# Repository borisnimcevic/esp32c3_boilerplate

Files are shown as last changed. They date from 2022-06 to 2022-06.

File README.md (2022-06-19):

# ESP32-C3 minimum components to start a project

### Motivation:
The plan is to copy this project every time a new project based on the esp32c3 starts.

### TODO:
* make a script for renaming all the relevant files for KiCAD to the name of the project
* Update the Bill Of materials

### Bill Of Materials
|Component  |Quantity |Link |
|----- |----- |-----  |
|ESP32-C3 |1 |[digikey](https://www.digikey.se/en/products/detail/espressif-systems/ESP32-C3/14115579) |
|or with embedded flash (ESP32-C3FN4) |1 |[digikey](https://www.digikey.se/en/products/detail/espressif-systems/ESP32-C3FN4/14115581) |
|FLASH 4MBIT |1 |[digikey](https://www.digikey.se/en/products/detail/winbond-electronics/W25Q16JVSSIM/12143335) |
|resistor 100 0402 |7 |[digikey](https://www.digikey.se/en/products/detail/yageo/RC0402FR-07100RP/4935263) |
|resistor 10k 0402 |1 |[digikey](https://www.digikey.se/en/products/detail/yageo/RC0402FR-0710KP/4935264) |
|LED red 0603|30 |[digikey](https://www.digikey.se/en/products/detail/osram-opto-semiconductors-inc/LS-Q976-NR-1/1227986) |
|LED transistor driver |4 |[digikey](https://www.digikey.se/en/products/detail/micro-commercial-co/MMBT5550-TP/10054662) |
|Ceramic antenna (chip antenna)|1 |[digikey](https://www.digikey.se/en/products/detail/johanson-technology-inc/2450AT18A100E/1560676) |
|Ceramic capacitor 1pF |1 |[digikey](https://www.digikey.se/en/products/detail/johanson-technology-inc/500R07S1R0BV4T/1561521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) |
|Ceramic capacitor 10nF |1 |[digikey](https://www.digikey.se/en/products/detail/tdk-corporation/CGA2B2X5R1E103M050BA/3949410) |
|Ceramic capacitor 100nF |1 |[digikey](https://www.digikey.se/en/products/detail/tdk-corporation/CGA2B1X7R1C104M050BC/3949478) |
|Ceramic capacitor 1uF |1 |[digikey](https://www.digikey.se/en/products/detail/kyocera-avx/04023D105KAT2A/13557232) |
|Ceramic capacitor 4.7uF |1 |[digikey](https://www.digikey.se/en/products/detail/yageo/CC0402KRX5R5BB475/7164360) |
|Ceramic inductor 2.7nH |1 |[digikey](https://www.digikey.se/en/products/detail/johanson-technology-inc/L-07C2N7SV6T/1830166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) |
|Ceramic inductor 3.9nH |1 |[digikey](https://www.digikey.se/en/products/detail/johanson-technology-inc/L-07C3N9SV6T/1915227) |
|Ceramic inductor 39nH |1 |[digikey](https://www.digikey.se/en/products/detail/johanson-technology-inc/L-07C39NJV6T/1915226) |

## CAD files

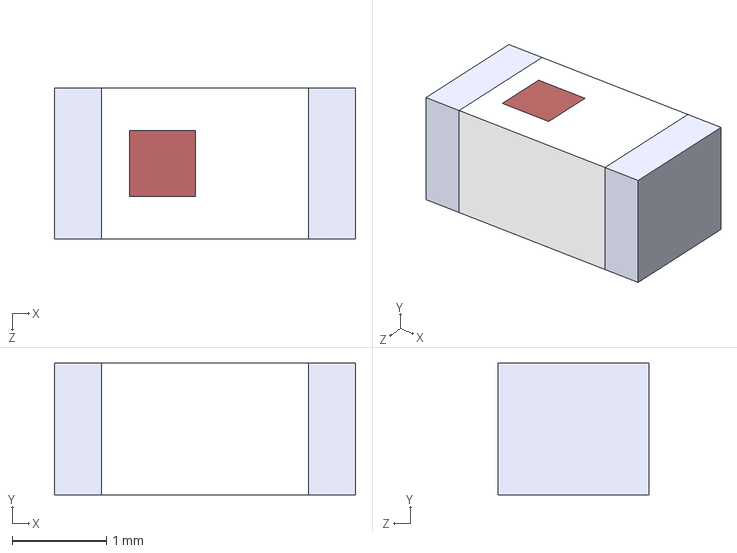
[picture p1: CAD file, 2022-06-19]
hardware/kicad-parts/ANT-2450AT18A100E/2450AT18A100E.step
3.20 x 1.40 x 1.60 mm

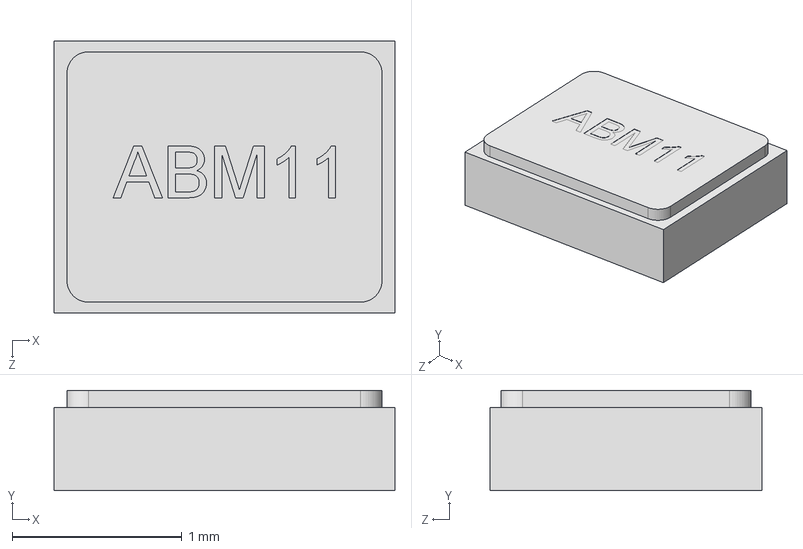
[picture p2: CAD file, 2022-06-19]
hardware/kicad-parts/Crystal/ABM1116.000MHZ-B7GT.STEP
2.01 x 0.59 x 1.60 mm

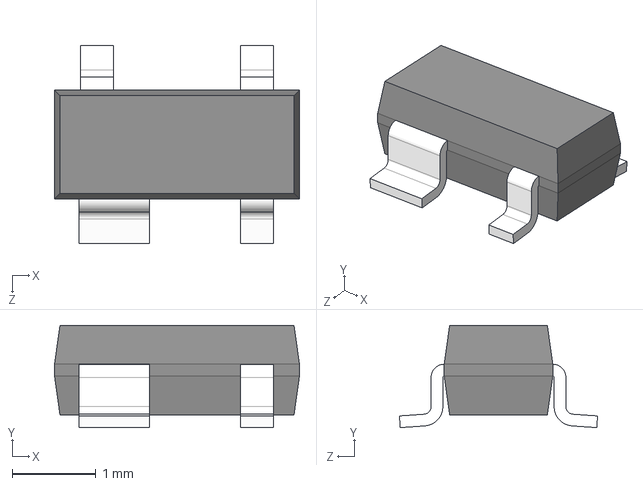
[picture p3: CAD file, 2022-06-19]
hardware/kicad-parts/ESD_protection-SR05/SR05.step
2.92 x 1.22 x 2.36 mm

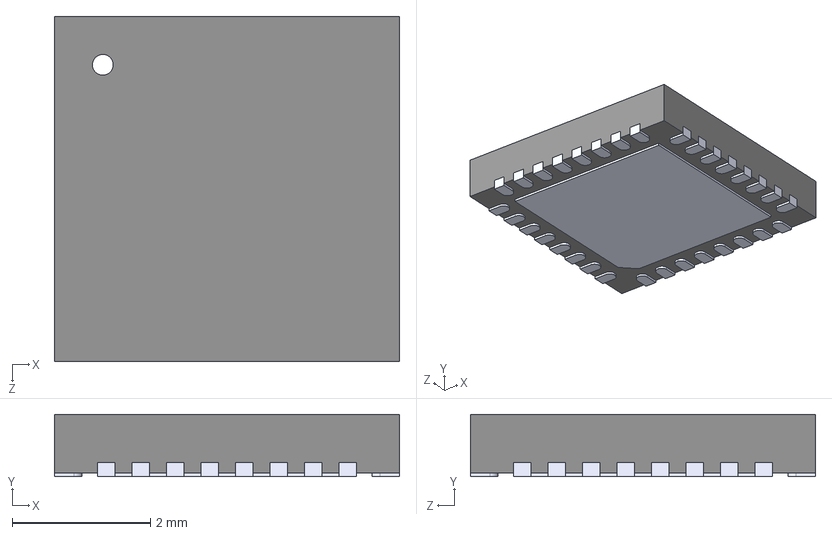
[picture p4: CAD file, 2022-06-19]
hardware/kicad-parts/ESP32-C3/ESP32-C3FH4.step
5.00 x 0.9 x 5.00 mm

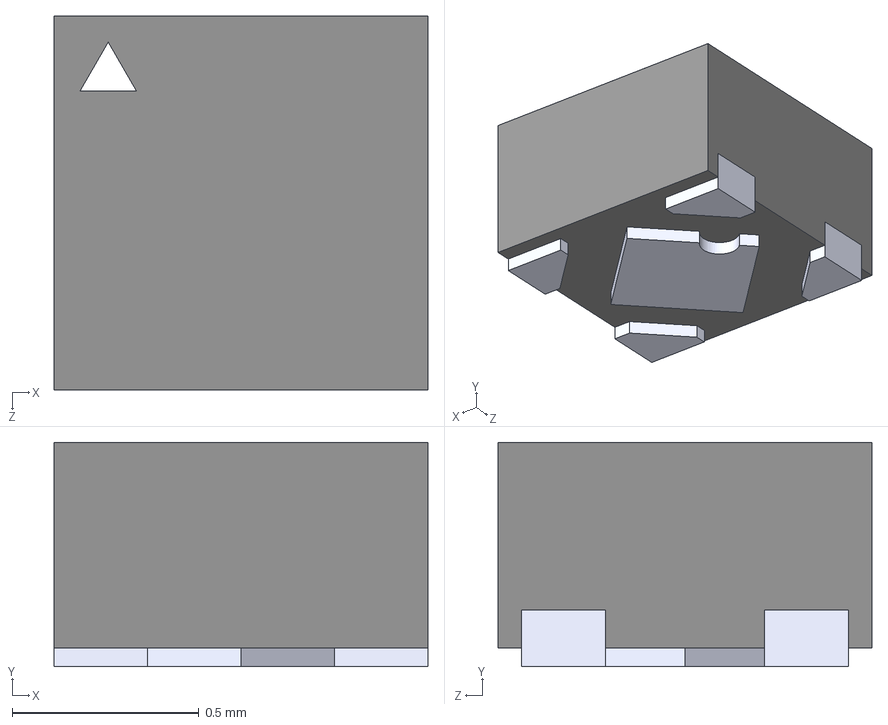
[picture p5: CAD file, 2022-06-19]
hardware/kicad-parts/LDO-MIC5524-3-3YMT-TZ/MIC5524-3.3YMT-TZ.step
1.00 x 0.6 x 1.00 mm

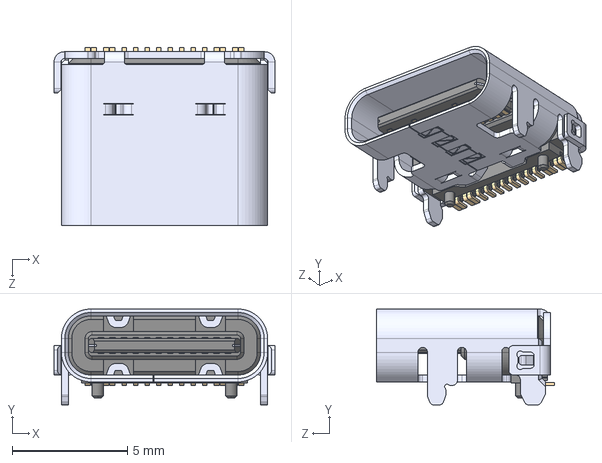
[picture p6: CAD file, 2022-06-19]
hardware/kicad-parts/USBC-USB4105-GF-A/USB4105-GF-A.step
9.58 x 4.16 x 7.71 mm

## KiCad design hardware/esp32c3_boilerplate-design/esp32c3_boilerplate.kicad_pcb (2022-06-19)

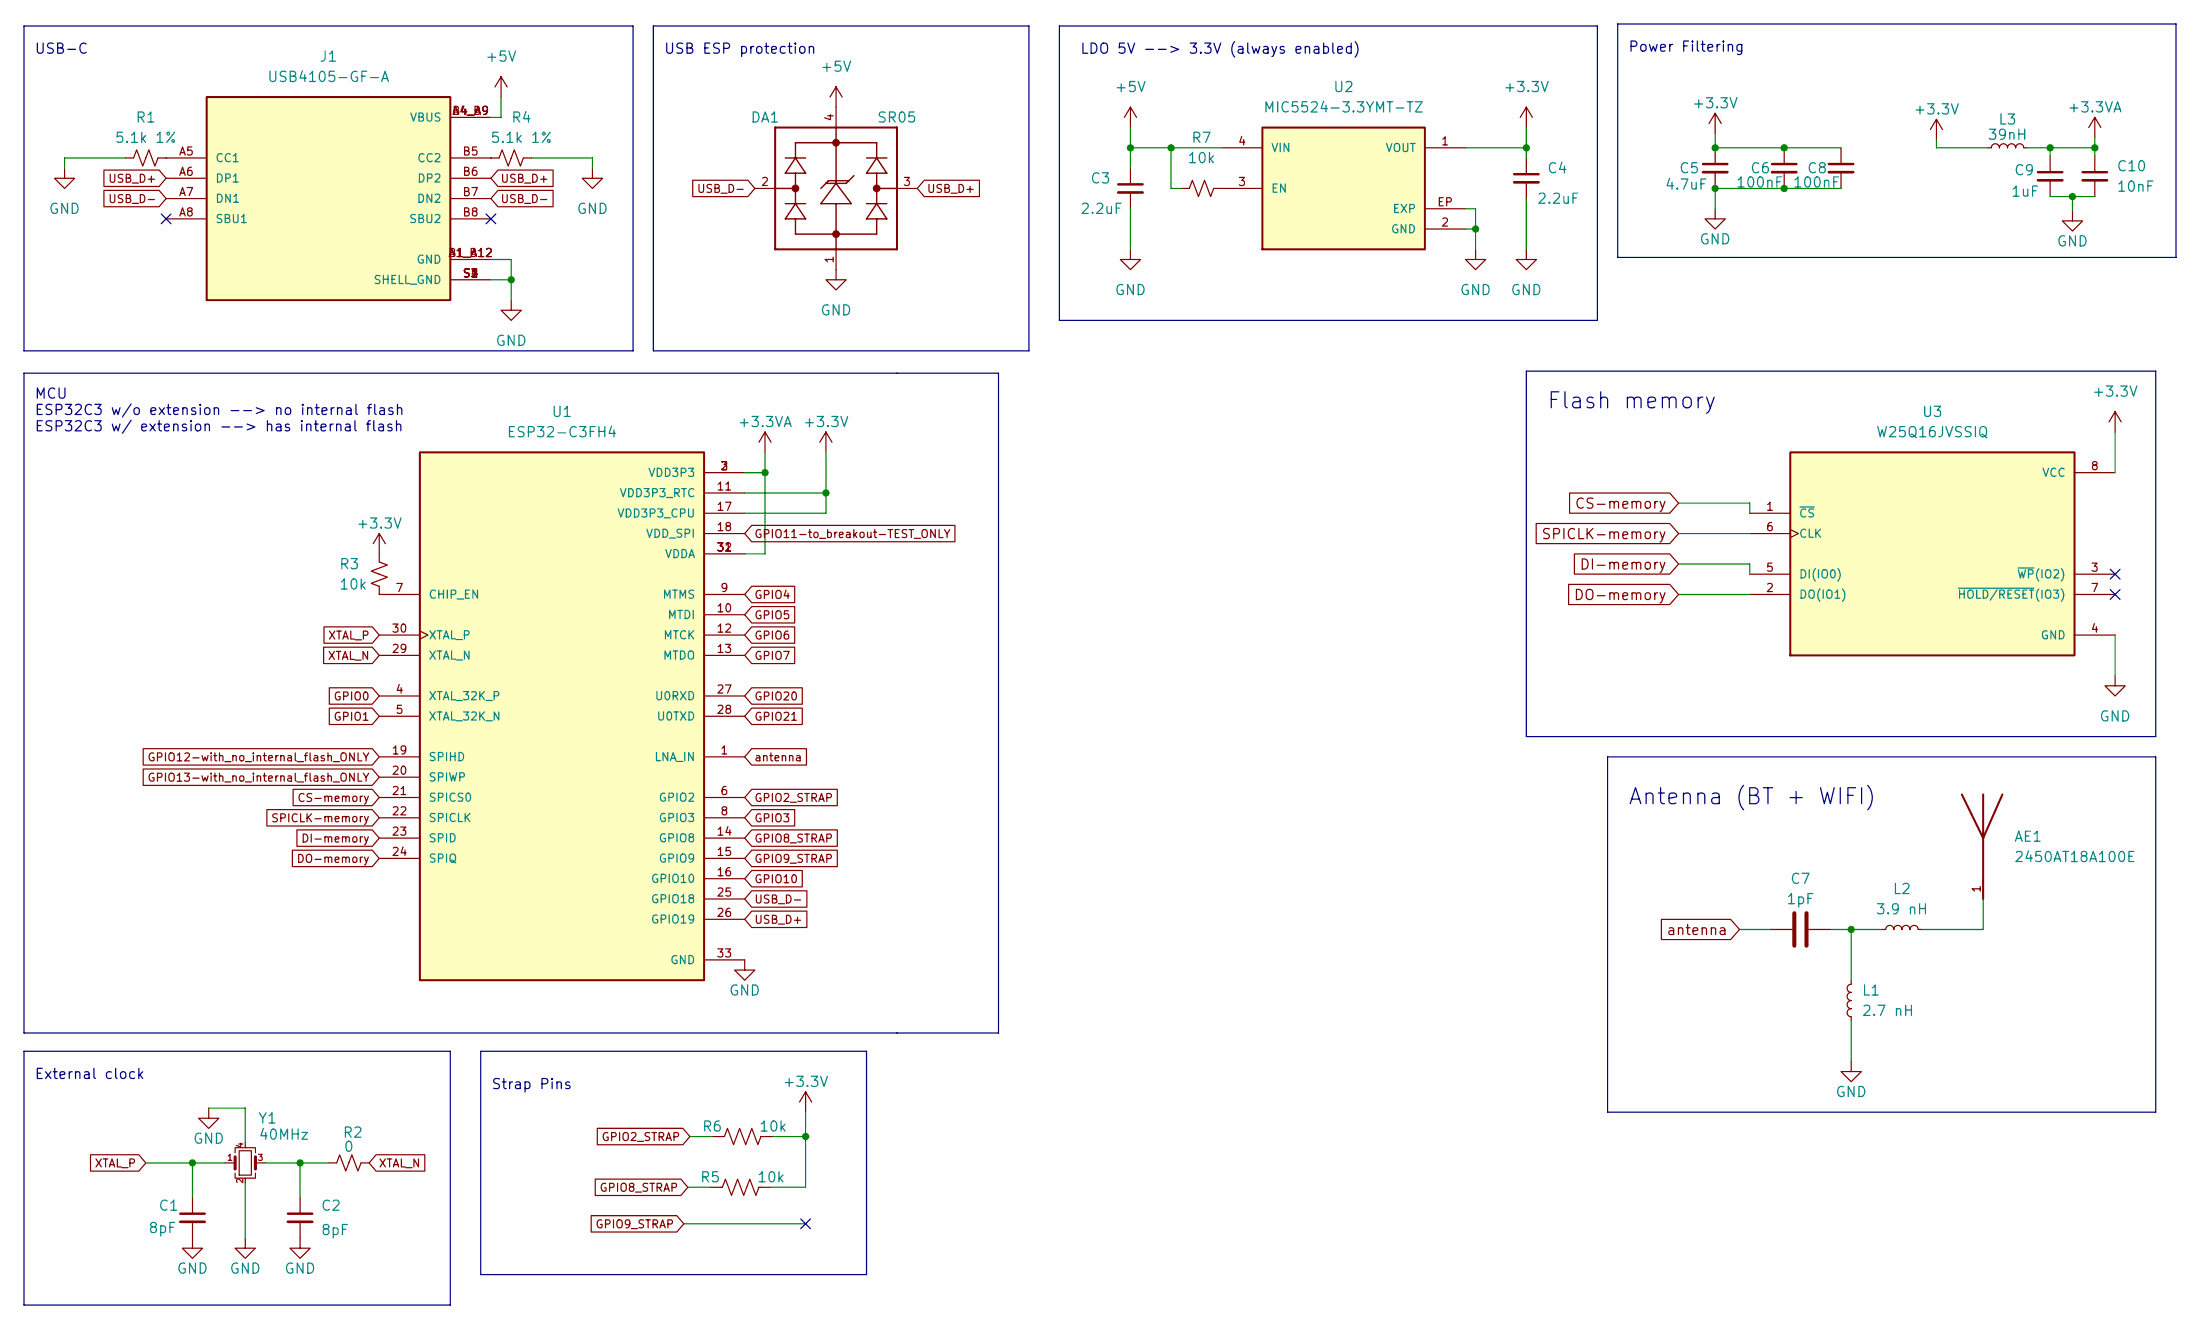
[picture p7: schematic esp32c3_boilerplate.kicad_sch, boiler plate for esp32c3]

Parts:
AE1: 2450AT18A100E; ANTC3216X140N; PARTREV 1.3
C1, C2: 8pF; C_0402_1005Metric_Pad0.74x0.62mm_HandSolder
C3, C4: 2.2uF; C_0402_1005Metric_Pad0.74x0.62mm_HandSolder
C5: 4.7uF; L_0402_1005Metric
C6, C8: 100nF; L_0402_1005Metric
C7: 1pF; C_0402_1005Metric
C9: 1uF; L_0402_1005Metric
C10: 10nF; L_0402_1005Metric
DA1: SR05; SOT143
J1: USB4105-GF-A; GCT_USB4105-GF-A; PARTREV A3
L1: 2.7 nH; L_0402_1005Metric
L2: 3.9 nH; L_0402_1005Metric
L3: 39nH; L_0402_1005Metric
R1, R4: 5.1k 1%; R_0402_1005Metric_Pad0.72x0.64mm_HandSolder
R2: 0; R_01005_0402Metric_Pad0.57x0.30mm_HandSolder
R3: 10k; R_01005_0402Metric_Pad0.57x0.30mm_HandSolder
R5, R6: 10k; R_0402_1005Metric
R7: 10k; R_0402_1005Metric_Pad0.72x0.64mm_HandSolder
U1: ESP32-C3FH4; QFN50P500X500X90-33N; PARTREV V1.0
U2: MIC5524-3.3YMT-TZ; VREG_MIC5524-3.3YMT-TZ; PARTREV 1.0
U3: W25Q16JVSSIQ; SOIC127P790X216-8N
Y1: 40MHz; Crystal_SMD_2016-4Pin_2.0x1.6mm

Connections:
+3.3VA: C9.1, C10.1, L3.2, U1.2 (VDD3P3), U1.3 (VDD3P3), U1.31 (VDDA), U1.32 (VDDA)
+3V3: C4.1, C5.1, C6.1, C8.1, L3.1, R3.1, R5.2, R6.2, U1.11 (VDD3P3_RTC), U1.17 (VDD3P3_CPU), U2.1 (VOUT), U3.8 (VCC)
+5V: C3.1, DA1.4, J1.A4_B9 (VBUS), J1.B4_A9 (VBUS), R7.1, U2.4 (VIN)
CS-memory: U1.21 (SPICS0), U3.1 (~CS)
DI-memory: U1.23 (SPID), U3.5 (DI(IO0))
DO-memory: U1.24 (SPIQ), U3.2 (DO(IO1))
GND: C1.2, C2.2, C3.2, C4.2, C5.2, C6.2, C8.2, C9.2, C10.2, DA1.1, J1.A1_B12 (GND), J1.B1_A12 (GND), J1.S1 (SHELL_GND), J1.S2 (SHELL_GND), J1.S3 (SHELL_GND), J1.S4 (SHELL_GND), L1.1, R1.1, R4.2, U1.33 (GND), U2.2 (GND), U2.EP (EXP), U3.4 (GND), Y1.2, Y1.4
GPIO0: U1.4 (XTAL_32K_P)
GPIO1: U1.5 (XTAL_32K_N)
GPIO2_STRAP: R6.1, U1.6 (GPIO2)
GPIO3: U1.8 (GPIO3)
GPIO4: U1.9 (MTMS)
GPIO5: U1.10 (MTDI)
GPIO6: U1.12 (MTCK)
GPIO7: U1.13 (MTDO)
GPIO8_STRAP: R5.1, U1.14 (GPIO8)
GPIO9_STRAP: U1.15 (GPIO9)
GPIO10: U1.16 (GPIO10)
GPIO11-to_breakout-TEST_ONLY: U1.18 (VDD_SPI)
GPIO12-with_no_internal_flash_ONLY: U1.19 (SPIHD)
GPIO13-with_no_internal_flash_ONLY: U1.20 (SPIWP)
GPIO20: U1.27 (U0RXD)
GPIO21: U1.28 (U0TXD)
unnamed: AE1.1, L2.2
unnamed: C2.1, R2.1, Y1.3
unnamed: C7.2, L1.2, L2.1
unnamed: J1.A5 (CC1), R1.2
unnamed: J1.B5 (CC2), R4.1
unnamed: R3.2, U1.7 (CHIP_EN)
unnamed: R7.2, U2.3 (EN)
SPICLK-memory: U1.22 (SPICLK), U3.6 (CLK)
USB_D+: DA1.3, J1.A6 (DP1), J1.B6 (DP2), U1.26 (GPIO19)
USB_D-: DA1.2, J1.A7 (DN1), J1.B7 (DN2), U1.25 (GPIO18)
XTAL_N: R2.2, U1.29 (XTAL_N)
XTAL_P: C1.1, U1.30 (XTAL_P), Y1.1
antenna: C7.1, U1.1 (LNA_IN)

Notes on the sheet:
USB-C
LDO 5V --> 3.3V (always enabled)
Flash memory
Power Filtering
Antenna (BT + WIFI)
External clock
MCU ESP32C3 w/o extension --> no internal flash ESP32C3 w/ extension --> has internal flash
Strap Pins
USB ESP protection

Board: 2 copper layers, 27 parts (0 on the bottom side), 22 nets, no tracks yet.

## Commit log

2022-06-19 Init repo
    [2450AT18A100E.step, ABM1116.000MHZ-B7GT.STEP, ESP32-C3FH4.step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]
2022-06-19 Relinked the libraries.
    [esp32c3_boilerplate.kicad_pcb, esp32c3_boilerplate.kicad_sch]
